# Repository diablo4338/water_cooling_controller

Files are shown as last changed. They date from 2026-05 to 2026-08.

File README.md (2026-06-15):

# PC Water Cooling Controller

An end-to-end fan controller solution built around a custom PCB and an `ESP32-C3` controller. The repository covers the full product scope: device firmware, a desktop application for Windows and Linux, PCB manufacturing files, and the bill of materials.

The controller is designed for:
- up to 4 fans;
- up to 4 `10k` thermistors.

The desktop application works over BLE and supports pairing mode, controller connection, telemetry monitoring, and cooling parameter updates. The hardware lives in `hardware/`, and the release pipeline builds a unified set of artifacts through [`.github/workflows/release.yml`](.github/workflows/release.yml).

## Repository structure
- [`firmware/`](firmware/README.md) - `ESP-IDF` firmware for `ESP32-C3`.
- [`pcwcc/`](pcwcc/README.md) - desktop GUI for Windows and Linux.
- [`hardware/`](hardware/README.md) - KiCad project, BOM, and production exports for the PCB.
- [`tests/raspberry/`](tests/raspberry/README.md) - Raspberry Pi helper for hardware integration tests.
- [`docker/`](docker/README.md) - local Docker environment for release-build verification.
- [`docs/`](docs/) - additional notes on architecture, CLI, release flow, and hardware.

## Release artifacts
The `scripts/make_release.sh` script and the `Release` workflow produce:
- firmware for `ESP32-C3`;
- a Linux `AppImage` for the desktop client;
- a production archive with `Gerber` and `drill` files for PCB manufacturing;
- checksums;
- the BOM is stored separately in [`hardware/production/bom/main.csv`](hardware/production/bom/main.csv).

Build details and structure notes are kept in the `README` files of the corresponding directories.

## License

This project is licensed for non-commercial use only.

Commercial use is not permitted without prior written permission from the author.

See [LICENSE](LICENSE) for details.

## Safety disclaimer

This is an experimental DIY hardware/software project. Use it at your own risk.
Incorrect wiring, firmware, configuration, or installation may cause hardware
damage, overheating, fire, or injury.

See [DISCLAIMER.md](DISCLAIMER.md).

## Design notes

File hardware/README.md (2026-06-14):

# Hardware

Hardware assets for the controller: the KiCad board project, PCB production files, and the bill of materials.

## Structure
- `kicad/` - KiCad project sources:
  - `main.kicad_pro` - project file;
  - `main.kicad_sch` - top-level schematic;
  - `main.kicad_pcb` - PCB;
  - additional schematic sheets: `ads`, `esp`, `fan_power`, `fans`, `ina`, `power`.
- `production/gerbers/` - `Gerber` files for board fabrication.
- `production/drill/` - drill files.
- `production/bom/main.csv` - BOM.
- `production/schematic-pdf/main.pdf` - schematic PDF export.

## Production artifacts
[`../scripts/build_hardware.sh`](../scripts/build_hardware.sh) builds the following archive in `dist/`:

```text
pc-water-cooling-controller-<version>-hardware-gerbers-drill.zip
```

It contains:
- all files from `production/gerbers/`;
- all files from `production/drill/`.

The BOM is kept in the repository separately and is not packed by this script, so it should be treated as an independent manufacturing artifact.

## Practical use
If the task is related to board manufacturing or revision work, this directory contains the working inputs:
- source files for schematic and PCB changes;
- ready-to-send fabrication exports;
- the current component list.

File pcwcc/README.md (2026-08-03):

# PCWCC

A desktop application for controlling the device over BLE. The GUI is built with `PySide6`, and the BLE layer uses `bleak`. The application runs on Linux and Windows; Linux releases are packaged as `AppImage`.

## Features
- scanning for the controller in pairing mode;
- pairing and subsequent application-level authorization;
- connecting to the device and reading temperatures in real time;
- reading and applying cooling parameters;
- BLE session diagnostics through debug mode.

Application-local data:
- `paired_devices.json` - trusted device database;
- `host_key.pem` - host private key used for pairing.

## Structure
- `src/pcwcc/core_logic/` - BLE protocol, codecs, pairing, control, and storage.
- `src/pcwcc/gui_logic/` - UI logic.
- `src/pcwcc/main.py` - entry point.
- `tests/` - unit and integration tests for the client.
- `packaging/` - desktop packaging assets.
- `pcwcc.spec` - `PyInstaller` configuration.

## Run

The application requires Python 3.11, 3.12, or 3.13. Python 3.14 is not
currently supported. Runtime and development dependencies are declared in
[`pyproject.toml`](pyproject.toml); the project does not use a separate
`requirements.txt`.

### Windows (PowerShell)

From the repository root, create a virtual environment using Python 3.13:

```powershell
py -3.13 -m venv .venv
```

Install the application and its development dependencies:

```powershell
.\.venv\Scripts\python.exe -m pip install --upgrade pip
.\.venv\Scripts\python.exe -m pip install -e ".\pcwcc[dev]"
```

Run the application:

```powershell
.\.venv\Scripts\python.exe -m pcwcc.main
```

Run it with extended BLE diagnostics:

```powershell
.\.venv\Scripts\python.exe -m pcwcc.main --debug
```

The editable installation (`-e`) means source code changes are picked up when
the application is restarted; reinstalling the package after each change is
not required.

If `py -3.13` reports that no suitable Python installation was found, install
64-bit Python 3.13 first, then repeat the commands above.

### Linux

From the `pcwcc/` directory, after installing the project dependencies:

```bash
python3 -m venv .venv
.venv/bin/python -m pip install -e ".[dev]"
PYTHONPATH=src python -m pcwcc.main
```

Alternatively, from the repository root:

```bash
make run-app
```

`make run-app` installs the application and its development dependencies from
`pcwcc/pyproject.toml` before starting it. To install without starting the GUI,
use:

```bash
make install-app
```

For extended BLE diagnostics:

```bash
make run-app APP_ARGS=--debug
```

## Tests
Unit tests:

```bash
PYTHONPATH=src python -m pytest -c pytest.ini -q -m "not integration"
```

Integration tests from the repository root:

```bash
PYTHONPATH=pcwcc/src python -m pytest -c pcwcc/pytest.ini -q -m integration
```

## Environment variables
Application:
- `BLE_SCAN_TIMEOUT_S`
- `BLE_RESOLVE_TIMEOUT_S`
- `BLE_CONNECT_TIMEOUT_S`
- `BLE_PAIR_TIMEOUT_S`
- `BLE_AUTH_TIMEOUT_S`
- `BLE_METRICS_TIMEOUT_S`
- `BLE_METRICS_RETRIES`
- `BLE_METRICS_RECONNECT_DELAY_S`
- `BLE_RESOLVE_BEFORE_CONNECT`
- `BLE_USE_SERVICE_FILTER`
- `BLE_WINRT_USE_CACHED_SERVICES`
- `BLE_WINRT_ADDRESS_TYPE`
- `GUI_ACTION_DEFAULT_TIMEOUT_S`
- `GUI_ACTION_SCAN_TIMEOUT_S`
- `GUI_ACTION_PAIR_TIMEOUT_S`
- `GUI_ACTION_CONNECT_TIMEOUT_S`
- `GUI_ACTION_DISCONNECT_TIMEOUT_S`

Integration tests:
- `BLE_ADDRESS`
- `BLE_ADAPTER`
- `SCAN_TIMEOUT_S`
- `CONNECT_TIMEOUT_S`
- `PRESS_BASE_URL`
- `PRESS_TIMEOUT_S`
- `PRESS_RETRIES`
- `PRESS_NO_RESPONSE`

## Packaging
The Linux `AppImage` is built by [`../scripts/build_appimage.sh`](../scripts/build_appimage.sh). Details are in [`packaging/appimage/README.md`](packaging/appimage/README.md).

### Windows executable

From the repository root, after installing the development dependencies, build
the Windows application with PyInstaller:

```powershell
.\.venv\Scripts\python.exe -m PyInstaller `
  --name PCWCC `
  --windowed `
  --onedir `
  --paths ".\pcwcc\src" `
  ".\pcwcc\src\pcwcc\main.py"
```

The executable is written to `dist\PCWCC\PCWCC.exe`. Windows builds disable
filtered and cached WinRT GATT service discovery by default to avoid
`ERROR_BAD_COMMAND (0x80070016)` with the controller. The behaviour can still
be overridden with `BLE_USE_SERVICE_FILTER` and
`BLE_WINRT_USE_CACHED_SERVICES`.

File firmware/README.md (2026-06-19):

# Firmware

`ESP-IDF` firmware for the `ESP32-C3` controller. It implements the BLE protocol, pairing and authorization, temperature acquisition from 4 channels, and control for 4 fans.

## Structure
- `src/ble_protocol/` - BLE services, GATT, pairing, control, and application logic.
- `src/metrics/` - temperature metric acquisition.
- `src/i2c_bus/` - shared I2C bus support.
- `tests/` - firmware tests enabled with `PAIR_RUN_TESTS=1`.
- `include/` - shared top-level headers if they need to be moved out of component-local structure.
- `sdkconfig`, `sdkconfig.defaults` - build configuration.

## Build and flash
From the repository root:

```bash
make fw
```

Manual `ESP-IDF` invocation:

```bash
. ~/esp/esp-idf/export.sh
idf.py -C firmware fullclean build flash
```

Test firmware:

```bash
make fw-test
```

This build enables `PAIR_RUN_TESTS=1`.

## Release output
[`scripts/build_firmware.sh`](../scripts/build_firmware.sh) builds and places the following into `dist/`:
- the main `.bin`;
- `.elf`;
- `.map`, if generated;
- `bootloader.bin`;
- `partition-table.bin`;
- a flashing note file.
- a `.zip` archive containing the full firmware artifact set.

## Related docs
- [`../docs/firmware.md`](../docs/firmware.md) - short firmware summary.
- [`../docs/architecture.md`](../docs/architecture.md) - architecture notes and protocol details.

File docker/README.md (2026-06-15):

# Docker release build config

Docker configuration for release builds used by the GitHub Actions [`Release`](../.github/workflows/release.yml) workflow. It defines the container environment for firmware and desktop packaging, including `Ubuntu 20.04`, `Python 3.12`, `OpenSSL 3`, `ESP-IDF`, AppImage tooling, and release artifact generation.

This is not the product runtime environment and not the main development flow. Its purpose is to provide the CI build environment and let the same release pipeline be reproduced locally when needed.

## Build the local image
From the `docker/` directory:

```bash
sudo docker build --no-cache \
  -t pcwcc-ubuntu20-build:local \
  -f Dockerfile.ubuntu20 .
```

After that, the expected flow is to run the release scripts from `scripts/` inside the container instead of assembling artifacts manually.

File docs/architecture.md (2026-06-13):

# Architecture

The project is a PC water cooling controller. The system consists of a GUI app (BLE client), device firmware, and a small HTTP service used by integration tests.

Key artifacts:
- `paired_devices.json` - trusted devices database on the host.
- `host_key.pem` - persistent host private key (P-256) used for pairing.

## App (pcwcc)
- `pcwcc/src/pcwcc/config.py` - loads configuration from env, shared timeouts/retries for BLE and GUI.
- `pcwcc/src/pcwcc/core.py` - public BLE API and protocol (pair/auth/metrics/config/operations). Used by GUI and tests.
- `pcwcc/src/pcwcc/presentation.py` - pure UI state logic (Actions, AppState, derive_ui).
- `pcwcc/src/pcwcc/gui.py` - PySide6 GUI and `BleWorker` that calls `BleAppCore`.
- `pcwcc/src/pcwcc/main.py` - minimal GUI entrypoint.
- `pcwcc/tests/` - unit and integration tests, run through `pcwcc/src/pcwcc/core.py`.

## Firmware (firmware/)
- `firmware/src/ble_protocol/app/main.c` - `app_main`, NVS, NimBLE, timers, metrics init.
- `firmware/src/ble_protocol/ble/gap.c` - advertising, connect/disconnect, PAIR/MAIN mode selection.
- `firmware/src/ble_protocol/ble/gatt.c` - GATT database (PAIR/MAIN/METRICS), read/write callbacks.
- `firmware/src/ble_protocol/ble/uuid.c` - UUID strings, firmware source of truth.
- `firmware/src/ble_protocol/pairing/state.c` - main access state machine (trusted/unauth/authed) and session handles.
- `firmware/src/ble_protocol/pairing/pair_state.c` - pairing flow steps.
- `firmware/src/ble_protocol/pairing/pair_mode.c` - separate 60-second pairing window and per-session ECDH material.
- `firmware/src/ble_protocol/pairing/conn_guard.c` - connection handle constraints.
- `firmware/src/ble_protocol/pairing/crypto.c`, `ecdh.c`, `host_verify.c` - cryptography and host identity checks.
- `firmware/src/ble_protocol/pairing/storage.c` - ring-buffer storage for up to 5 trusted host/key entries in NVS.
- `firmware/src/ble_protocol/ble/metrics_ble.c` - notify/handle metrics over BLE.
- `firmware/src/metrics/` - metrics source (ADS1115 and aggregation).
- `firmware/tests/` - firmware test sources compiled when `PAIR_RUN_TESTS=1`.
- `firmware/build/` - ESP-IDF build artifacts.

## Support service (tests/raspberry/)
- `tests/raspberry/app.py` - HTTP endpoint for the Raspberry Pi GPIO button, used by integration tests.

## BLE protocol surface
GATT services are split by responsibility:
- `PAIR_SVC` - pairing and initial key exchange.
- `MAIN_SVC` - authorization before data access.
- `METRICS_SVC` - temperature metrics (notify).
- `CONFIG_SVC` - cooling system parameters and status.
- `OPERATIONS_SVC` - maintenance operations (for example, fan calibration).

UUID constants must be synchronized between firmware (`firmware/src/ble_protocol/ble/uuid.c`) and the app (`pcwcc/src/pcwcc/core.py`).

## Public API Contract
Any changes in `pcwcc/src/pcwcc/core.py` must be reflected in tests and the GUI. This file is the source of truth for BLE behavior.
UUID constants in `pcwcc/src/pcwcc/core.py` must match `firmware/src/ble_protocol/ble/uuid.c`.
Actions from `pcwcc/src/pcwcc/presentation.py` are the public contract between the GUI and UI logic. Renaming Actions requires updating UI bindings and tests.
All interactive GUI elements are tagged with `actionId = Action.name` and used for smoke checks.

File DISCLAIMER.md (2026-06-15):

# Disclaimer

This project is an experimental DIY hardware and software project.

It is provided without any warranty. Use it at your own risk.

Incorrect wiring, firmware bugs, incorrect configuration, component failure, or
improper installation may cause overheating, hardware damage, fire, electric
shock, data loss, injury, or other damage.

The author is not responsible for any damage, loss, injury, fire, electrical
failure, or other consequences caused by building, modifying, installing, or
using this project.

You are responsible for checking the design, selecting appropriate components,
adding fuses and protections, testing the device, and ensuring that it is safe
for your use case.

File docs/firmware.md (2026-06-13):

# Firmware

The ESP-IDF project lives under `firmware/`.

- Components: `firmware/src/ble_protocol`, `firmware/src/metrics`, `firmware/src/i2c_bus`
- Firmware tests: `firmware/tests/`
- Build entry: `firmware/CMakeLists.txt`
- Active config: `firmware/sdkconfig`

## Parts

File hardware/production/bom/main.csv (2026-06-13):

Reference | Qty | Value | DNP | Exclude from BOM | Exclude from Board | Footprint | Datasheet
BZ1 | 1 | Buzzer |  |  |  | Connector_PinHeader_2.54mm:PinHeader_1x02_P2.54mm_Vertical
C1,C2,C3,C4,C8,C9,C20 | 7 | 0.1 |  |  |  | Capacitor_SMD:C_0805_2012Metric_Pad1.18x1.45mm_HandSolder
C5 | 1 | 4.7 |  |  |  | Capacitor_SMD:C_0805_2012Metric_Pad1.18x1.45mm_HandSolder
C6,C7,C25 | 3 | 1 |  |  |  | Capacitor_SMD:C_0805_2012Metric_Pad1.18x1.45mm_HandSolder
C10 | 1 | 280 |  |  |  | Capacitor_THT:CP_Radial_D8.0mm_P3.50mm
C17,C18,C19,C22,C23,C24 | 6 | 10 |  |  |  | Capacitor_SMD:C_0805_2012Metric_Pad1.18x1.45mm_HandSolder
C21 | 1 | 10p |  |  |  | Capacitor_SMD:C_0805_2012Metric_Pad1.18x1.45mm_HandSolder
D1 | 1 | D_Small |  |  |  | Diode_SMD:D_0805_2012Metric_Pad1.15x1.40mm_HandSolder
D2 | 1 | PD3S120LQ |  |  |  | Custom:323_2
D3 | 1 | 1N4148WS-HG3_A-08 |  |  |  | Diode_SMD:D_SOD-323_HandSoldering | https://www.diodes.com/assets/Datasheets/ds30396.pdf
J1,J2,J3,J4 | 4 | Conn_01x02_Pin |  |  |  | Connector_PinHeader_2.54mm:PinHeader_1x02_P2.54mm_Horizontal
J5,J6,J7,J8 | 4 | Conn_01x04_Pin |  |  |  | Connector:FanPinHeader_1x04_P2.54mm_Vertical
J9,J10 | 2 | Conn_01x03_Socket |  |  |  | Connector_PinHeader_2.54mm:PinHeader_1x02_P2.54mm_Vertical
J11 | 1 | Conn_01x03_Socket |  |  |  | Custom:sata
L1 | 1 | DE1207-56(DR125-560-R EATON ELECTRONICS) |  |  |  | Custom:SRN4018
Q1 | 1 | MMFTP3334K |  |  |  | Package_TO_SOT_SMD:SOT-23-3 | https://ngspice.sourceforge.io/docs/ngspice-html-manual/manual.xhtml#cha_MOSFETs
Q2,Q3 | 2 | NXV40UNR |  |  |  | Package_TO_SOT_SMD:SOT-23-3 | https://ngspice.sourceforge.io/docs/ngspice-html-manual/manual.xhtml#cha_MOSFETs
Q4 | 1 | BCV71 |  |  |  | Package_TO_SOT_SMD:SOT-23-3 | https://ngspice.sourceforge.io/docs/ngspice-html-manual/manual.xhtml#cha_BJTs
R1,R2,R3,R4 | 4 | 330 |  |  |  | Resistor_SMD:R_0805_2012Metric_Pad1.20x1.40mm_HandSolder
R5,R6,R7,R8,R9,R14,R20,R24,R25,R30 | 10 | 4k7 |  |  |  | Resistor_SMD:R_0805_2012Metric_Pad1.20x1.40mm_HandSolder
R10,R12,R18,R19,R23,R27,R34,R36 | 8 | 100k |  |  |  | Resistor_SMD:R_0805_2012Metric_Pad1.20x1.40mm_HandSolder
R11,R13 | 2 | 2k2 |  |  |  | Resistor_SMD:R_0805_2012Metric_Pad1.20x1.40mm_HandSolder
R15,R16,R33 | 3 | 1k |  |  |  | Resistor_SMD:R_0805_2012Metric_Pad1.20x1.40mm_HandSolder
R17 | 1 | WSL2512R0470FEA |  |  |  | Resistor_SMD:R_2512_6332Metric_Pad1.40x3.35mm_HandSolder
R21 | 1 | 124k |  |  |  | Resistor_SMD:R_0805_2012Metric_Pad1.20x1.40mm_HandSolder
R22 | 1 | 10k |  |  |  | Resistor_SMD:R_0805_2012Metric_Pad1.20x1.40mm_HandSolder
R26,R35 | 2 | 100 |  |  |  | Resistor_SMD:R_0805_2012Metric_Pad1.20x1.40mm_HandSolder
R28 | 1 | 4k02 |  |  |  | Resistor_SMD:R_0805_2012Metric_Pad1.20x1.40mm_HandSolder
R29 | 1 | 61k9 |  |  |  | Resistor_SMD:R_0805_2012Metric_Pad1.20x1.40mm_HandSolder
R31,R32 | 2 | 10 |  |  |  | Resistor_SMD:R_0805_2012Metric_Pad1.20x1.40mm_HandSolder
SW1 | 1 | PAIR |  |  |  | Custom:smd button
SW2 | 1 | RESET |  |  |  | Custom:smd button
SW3 | 1 | BOOT |  |  |  | Custom:smd button
U1 | 1 | ESP32-C3-WROOM-02 |  |  |  | RF_Module:ESP32-C3-WROOM-02 | https://www.espressif.com/sites/default/files/documentation/esp32-c3-wroom-02_datasheet_en.pdf
U2 | 1 | TPS7A02-3.3 |  |  |  | Package_TO_SOT_SMD:SOT-23-5 | https://www.ti.com/lit/ds/symlink/tps7a05.pdf
U3 | 1 | TMUX1104DGSR |  |  |  | Ti:DGS0010A-IPC_C | https://www.ti.com/lit/gpn/tmux1104
U4 | 1 | ADS1115IDGS |  |  |  | Ti:DGS0010A_N | http://www.ti.com/lit/ds/symlink/ads1113.pdf
U5 | 1 | MCP16331T-E/CH |  |  |  | Package_TO_SOT_SMD:SOT-23-6 | http://ww1.microchip.com/downloads/en/DeviceDoc/20005308C.pdf
U6 | 1 | INA226 |  |  |  | Package_SO:VSSOP-10_3x3mm_P0.5mm | http://www.ti.com/lit/ds/symlink/ina226.pdf

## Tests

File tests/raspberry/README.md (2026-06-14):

# Raspberry button test helper

A small `FastAPI` service for Raspberry Pi that simulates a long hardware-button press over GPIO. It is used by integration tests when the controller must be switched into pairing mode without manual intervention.

## Contents
- `app.py` - HTTP endpoint `GET /press/reset-long` that drives the GPIO pin.
- `requirements.txt` - Raspberry Pi dependencies: `fastapi`, `uvicorn`, `RPi.GPIO`.

## Wiring
- GPIO mode: `BCM`;
- output pin in code: `GPIO_PIN = 17`;
- Raspberry Pi physical header pin for `BCM 17`: `11`;
- signal level: `3.3V`;
- common `GND` between the Raspberry Pi and the target board is required.

The service holds `BCM 17` at `HIGH` for `5.0` seconds and then returns the line to `LOW`.

## Run
From the repository root:

```bash
uvicorn tests.raspberry.app:app --host 0.0.0.0 --port 8001
```

or:

```bash
make run-buttons
```

## Constraints
- `RPi.GPIO` only works on Raspberry Pi with GPIO access;
- if the target board input is not `3.3V` tolerant, use proper level shifting or interface circuitry.

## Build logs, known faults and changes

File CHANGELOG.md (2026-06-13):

# Changelog

## Unreleased
- Restructured repository layout into `docs/`, `pcwcc/src/`, and `firmware/src/`.

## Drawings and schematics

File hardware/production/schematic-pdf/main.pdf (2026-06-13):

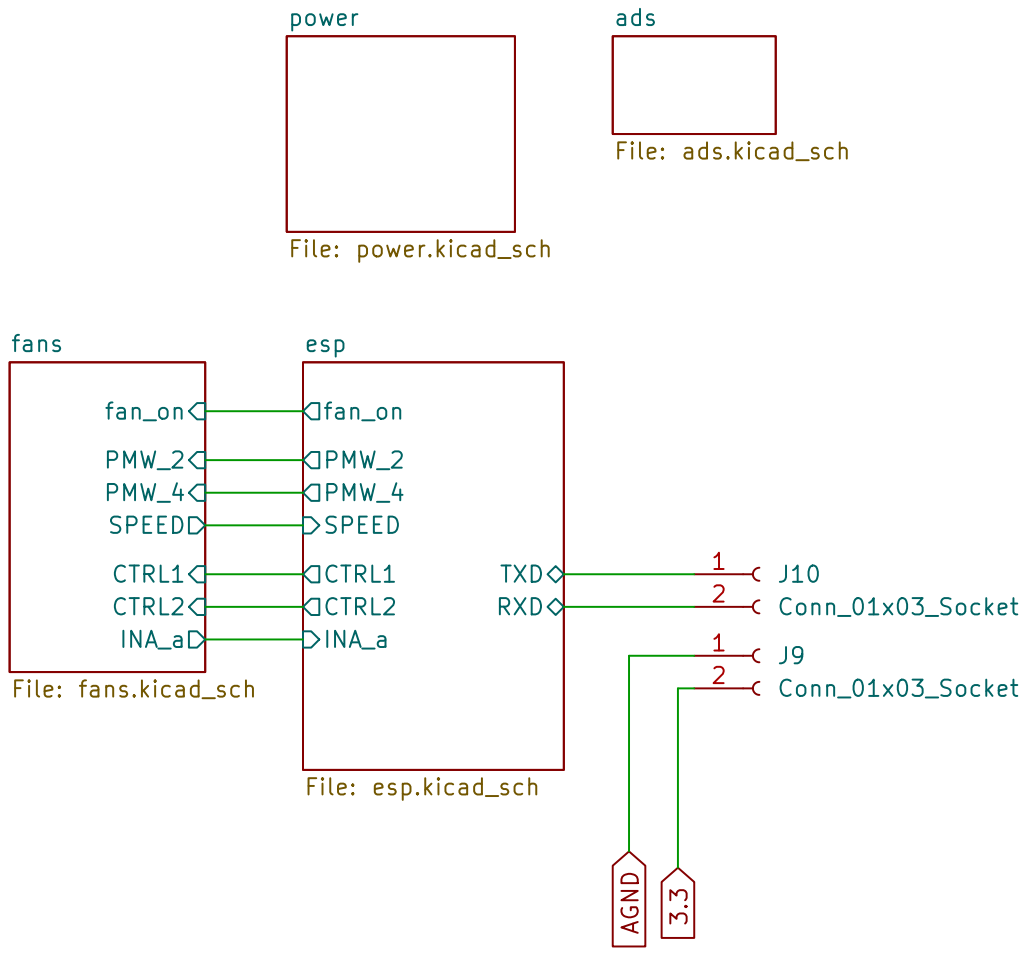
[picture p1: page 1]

Size: A4 | Rev:
KiCad E.D.A. 10.0.3 | Id: 1/7

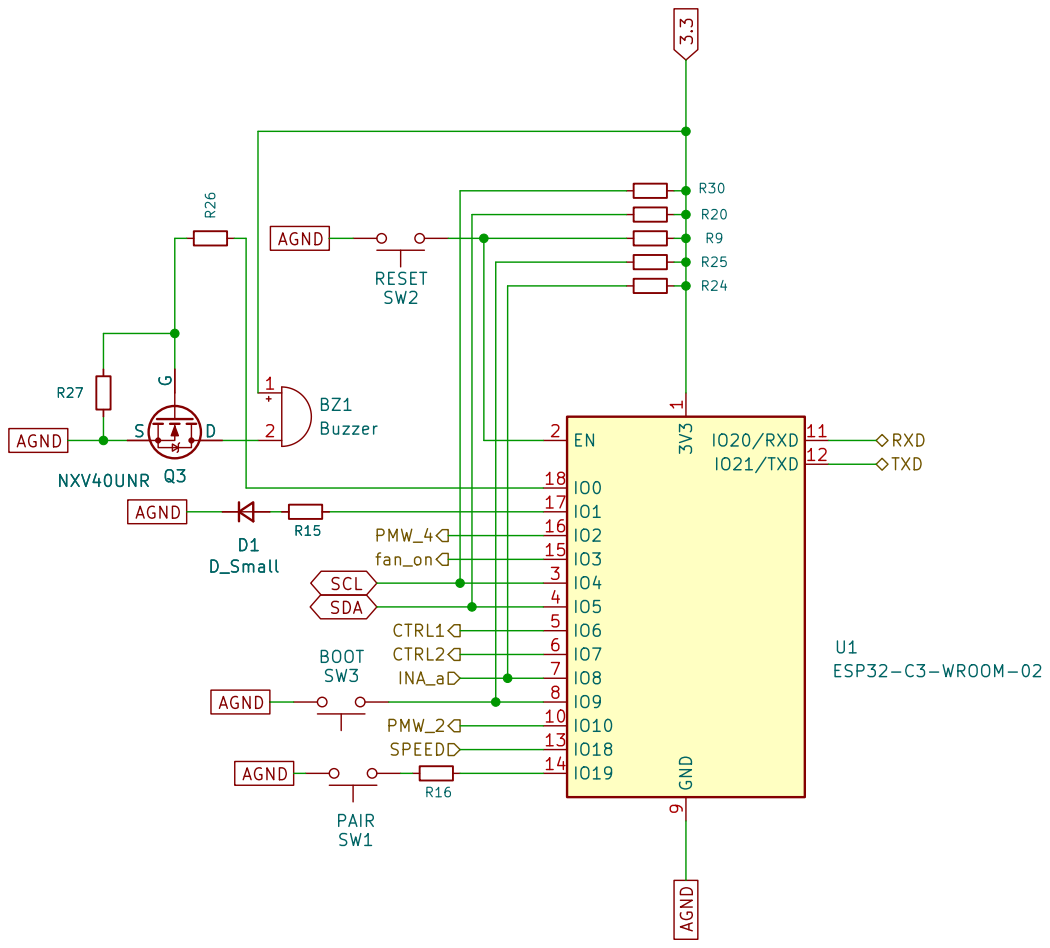
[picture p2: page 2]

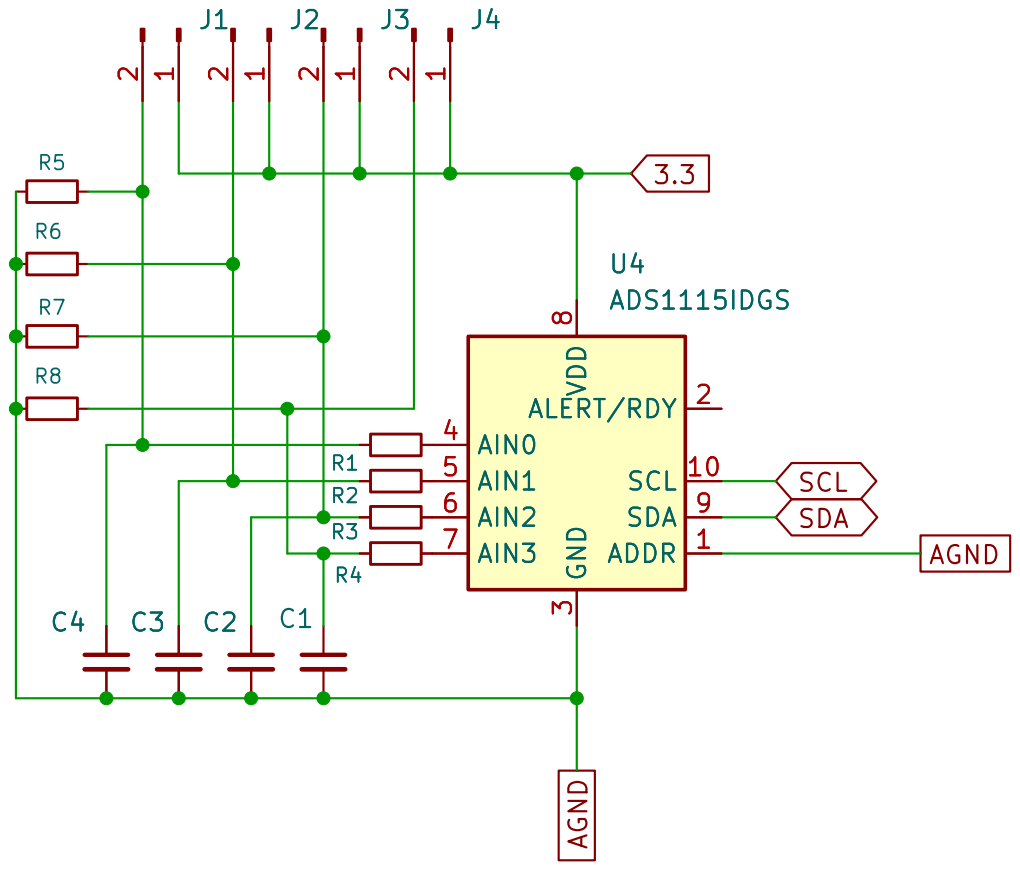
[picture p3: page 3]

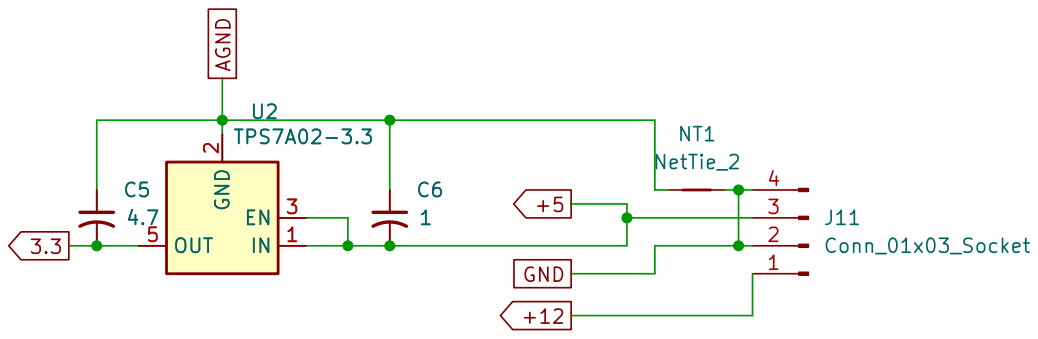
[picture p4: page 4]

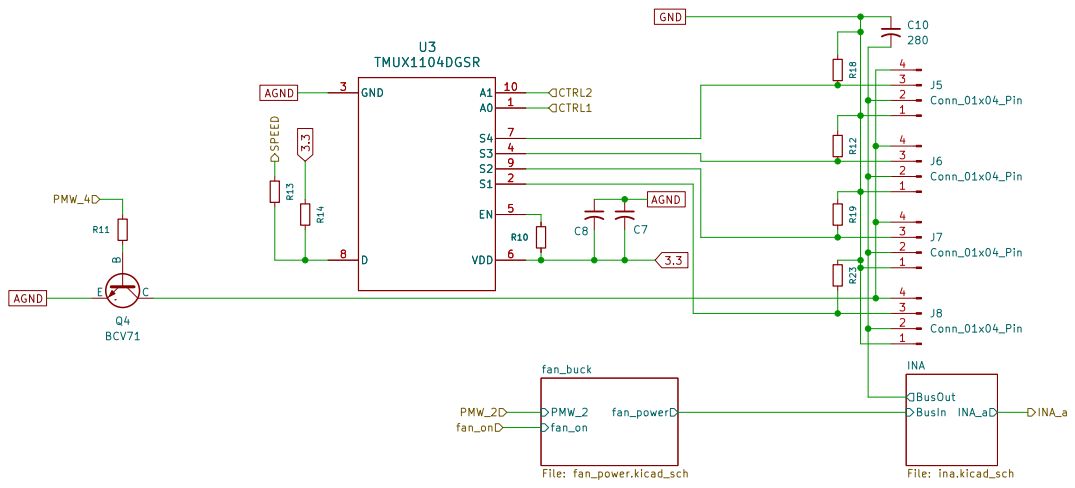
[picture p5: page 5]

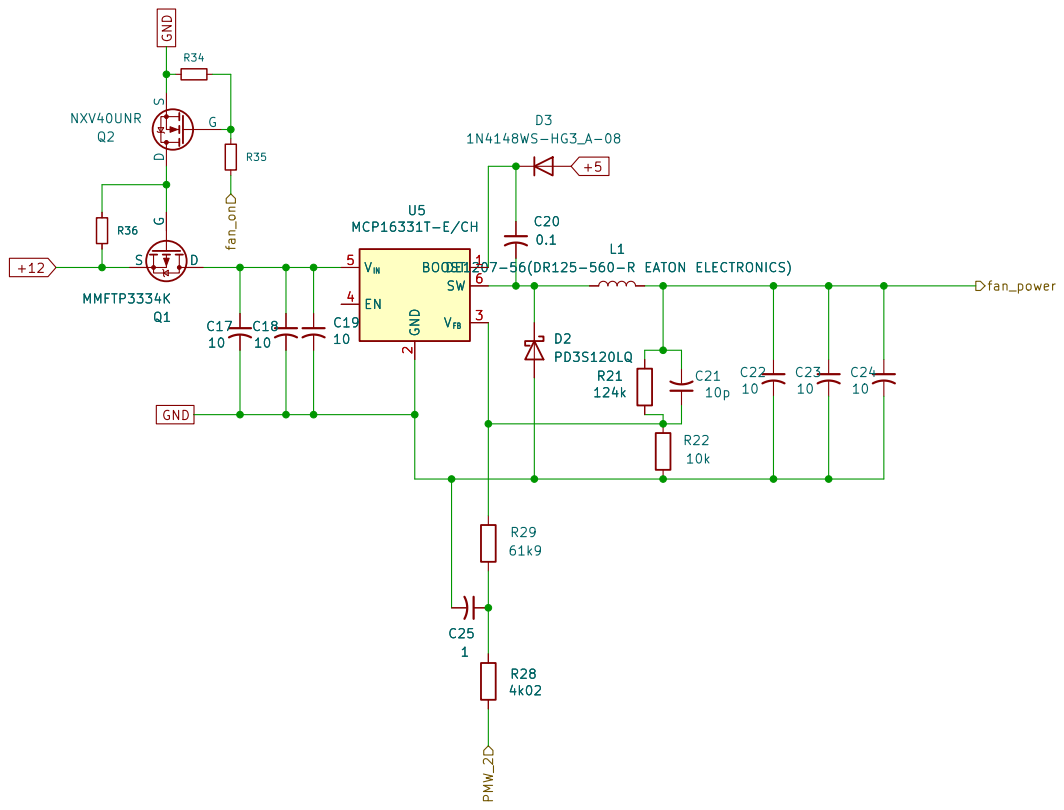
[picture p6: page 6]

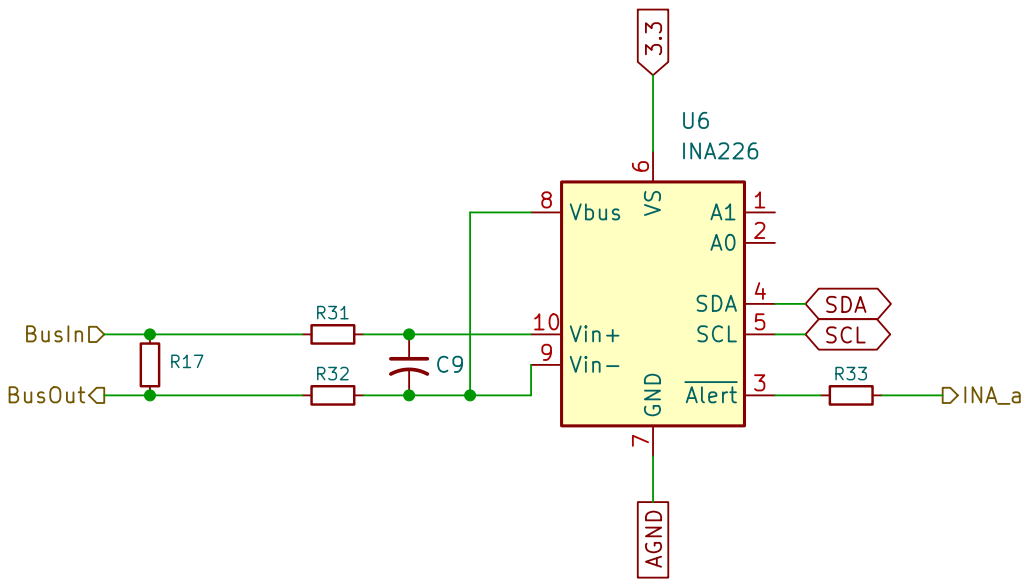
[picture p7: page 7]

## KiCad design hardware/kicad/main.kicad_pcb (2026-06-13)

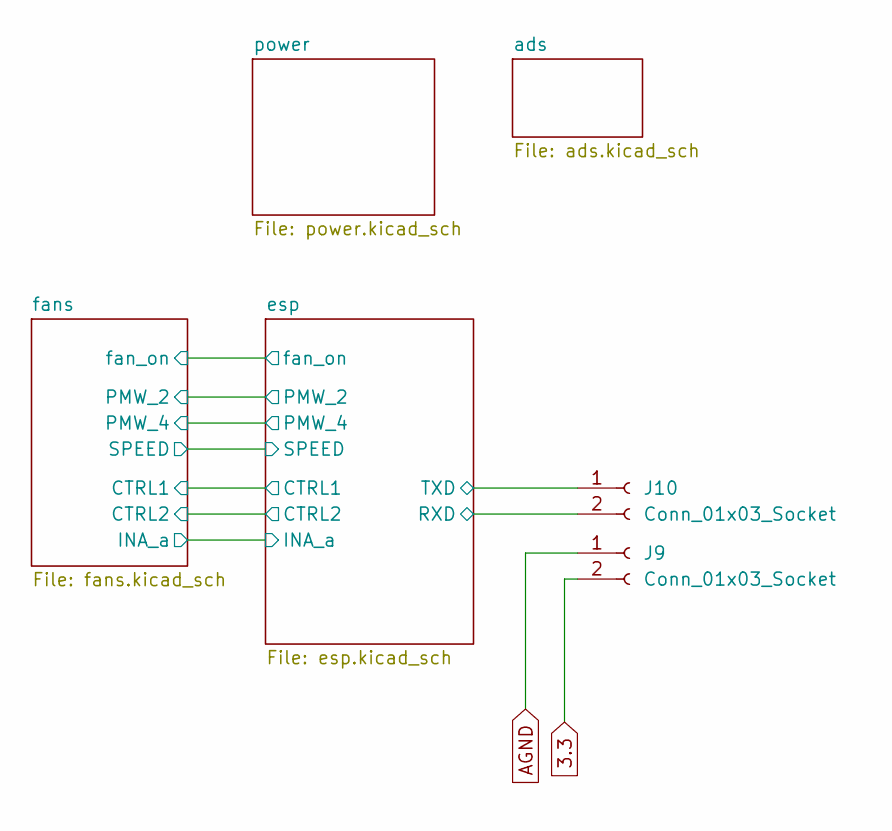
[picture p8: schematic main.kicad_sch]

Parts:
J9, J10: Conn_01x03_Socket; PinHeader_1x02_P2.54mm_Vertical

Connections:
3.3: J9.2; also elsewhere on the board
/esp/RXD: J10.2; also elsewhere on the board
/esp/TXD: J10.1; also elsewhere on the board
AGND: J9.1; also elsewhere on the board

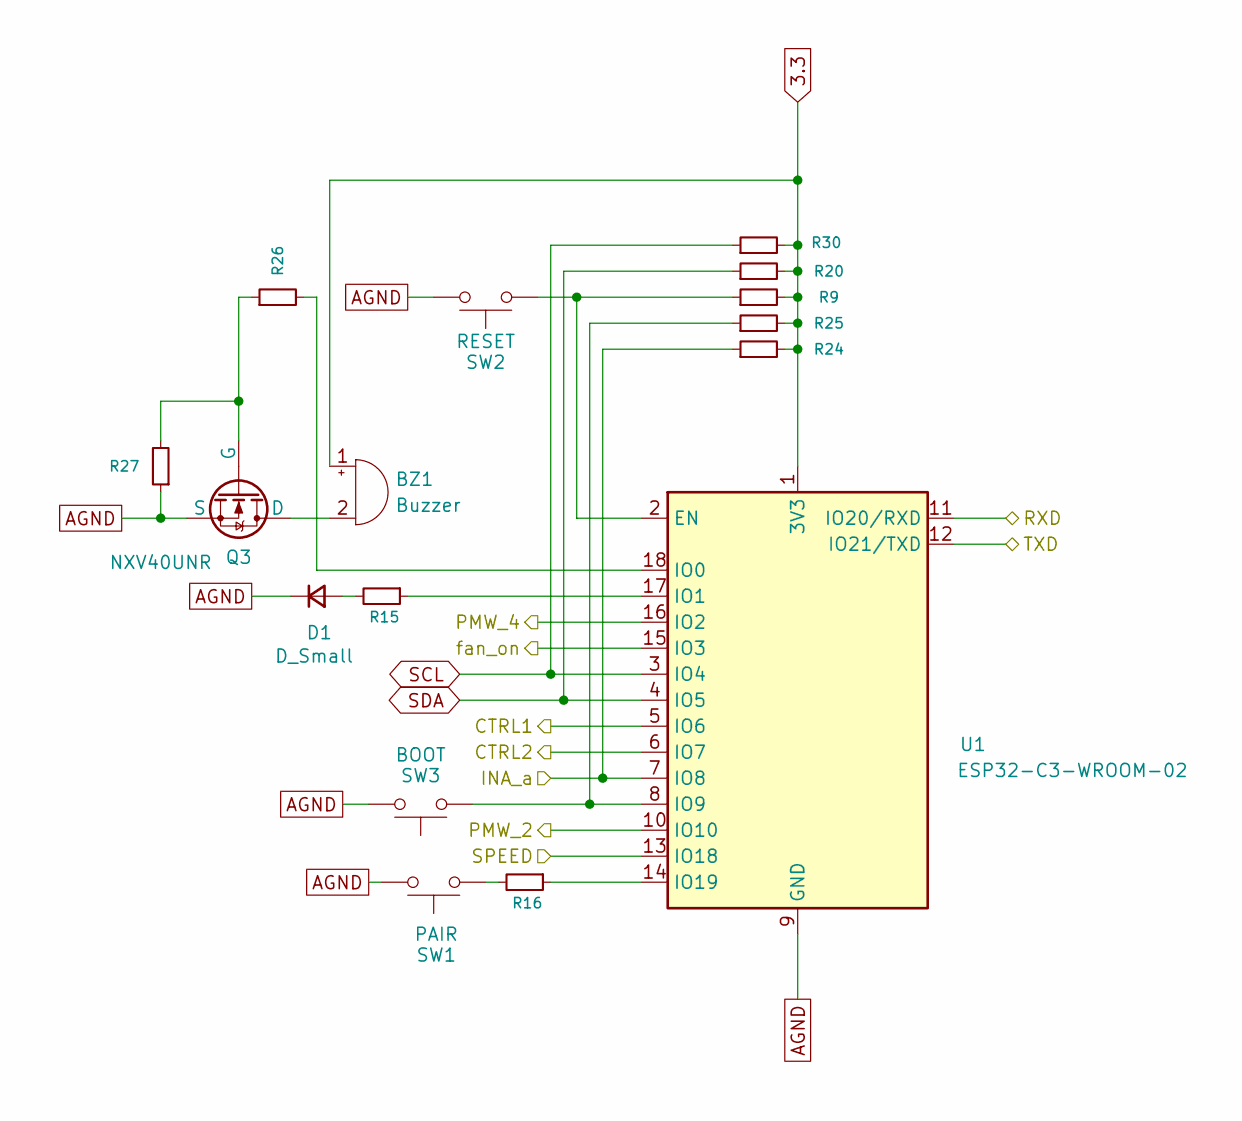
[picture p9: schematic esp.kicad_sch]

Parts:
BZ1: Buzzer; PinHeader_1x02_P2.54mm_Vertical
D1: D_Small; D_0805_2012Metric_Pad1.15x1.40mm_HandSolder
Q3: NXV40UNR; SOT-23-3
R9, R20, R24, R25, R30: 4k7; R_0805_2012Metric_Pad1.20x1.40mm_HandSolder
R15, R16: 1k; R_0805_2012Metric_Pad1.20x1.40mm_HandSolder
R26: 100; R_0805_2012Metric_Pad1.20x1.40mm_HandSolder
R27: 100k; R_0805_2012Metric_Pad1.20x1.40mm_HandSolder
SW1: PAIR; smd button
SW2: RESET; smd button
SW3: BOOT; smd button
U1: ESP32-C3-WROOM-02

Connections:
3.3: BZ1.1 (+), R9.2, R20.2, R24.2, R25.2, R30.2, U1.1 (3V3); also elsewhere on the board
/esp/CTRL1: U1.5 (IO6); also elsewhere on the board
/esp/CTRL2: U1.6 (IO7); also elsewhere on the board
/esp/INA_a: R24.1, U1.7 (IO8); also elsewhere on the board
/esp/PMW_2: U1.10 (IO10); also elsewhere on the board
/esp/PMW_4: U1.16 (IO2); also elsewhere on the board
/esp/RXD: U1.11 (IO20/RXD); also elsewhere on the board
/esp/SPEED: U1.13 (IO18); also elsewhere on the board
/esp/TXD: U1.12 (IO21/TXD); also elsewhere on the board
/esp/fan_on: U1.15 (IO3); also elsewhere on the board
AGND: D1.1 (K), Q3.2 (S), R27.1, SW1.2, SW2.2, SW3.2, U1.9 (GND), U1.19 (GND); also elsewhere on the board
unnamed: BZ1.2 (-), Q3.3 (D)
unnamed: D1.2 (A), R15.2
unnamed: Q3.1 (G), R26.1, R27.2
unnamed: R16.2, SW1.1
unnamed: R9.1, SW2.1, U1.2 (EN)
unnamed: R26.2, U1.18 (IO0)
unnamed: R15.1, U1.17 (IO1)
unnamed: R25.1, SW3.1, U1.8 (IO9)
unnamed: R16.1, U1.14 (IO19)
SCL: R30.1, U1.3 (IO4); also elsewhere on the board
SDA: R20.1, U1.4 (IO5); also elsewhere on the board

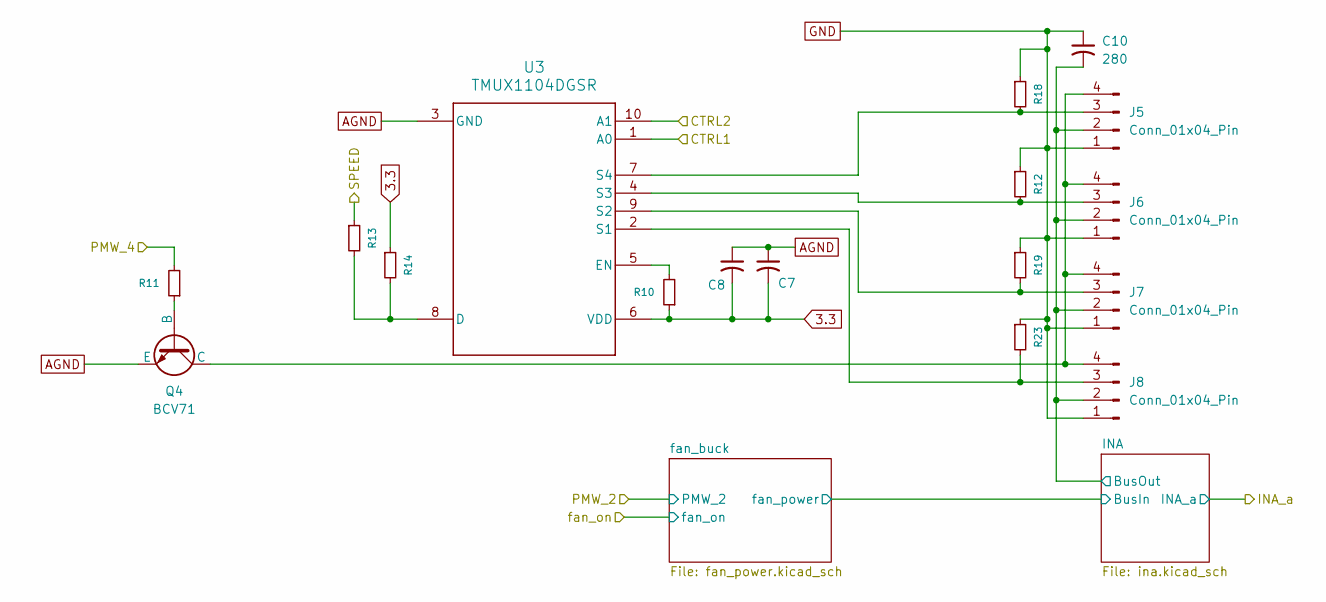
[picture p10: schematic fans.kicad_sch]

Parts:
C7: 1; C_0805_2012Metric_Pad1.18x1.45mm_HandSolder
C8: 0.1; C_0805_2012Metric_Pad1.18x1.45mm_HandSolder
C10: 280; CP_Radial_D8.0mm_P3.50mm
J5, J6, J7, J8: Conn_01x04_Pin; FanPinHeader_1x04_P2.54mm_Vertical
Q4: BCV71; SOT-23-3
R10, R12, R18, R19, R23: 100k; R_0805_2012Metric_Pad1.20x1.40mm_HandSolder
R11, R13: 2k2; R_0805_2012Metric_Pad1.20x1.40mm_HandSolder
R14: 4k7; R_0805_2012Metric_Pad1.20x1.40mm_HandSolder
U3: TMUX1104DGSR; DGS0010A-IPC_C

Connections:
3.3: C7.2, C8.2, R10.1, R14.1, U3.6 (VDD); also elsewhere on the board
/esp/CTRL1: U3.1 (A0); also elsewhere on the board
/esp/CTRL2: U3.10 (A1); also elsewhere on the board
/esp/PMW_4: R11.2; also elsewhere on the board
/esp/SPEED: R13.1; also elsewhere on the board
/fans/INA/BusOut: C10.2, J5.2 (VCC), J6.2 (VCC), J7.2 (VCC), J8.2 (VCC); also elsewhere on the board
AGND: C7.1, C8.1, Q4.2 (E), U3.3 (GND); also elsewhere on the board
GND: C10.1, J5.1 (GND), J6.1 (GND), J7.1 (GND), J8.1 (GND), R12.1, R18.1, R19.1, R23.1; also elsewhere on the board
unnamed: J5.4 (PMW), J6.4 (PMW), J7.4 (PMW), J8.4 (PMW), Q4.3 (C)
unnamed: J5.3 (TAHO), R18.2, U3.7 (S4)
unnamed: J6.3 (TAHO), R12.2, U3.4 (S3)
unnamed: J7.3 (TAHO), R19.2, U3.9 (S2)
unnamed: J8.3 (TAHO), R23.2, U3.2 (S1)
unnamed: Q4.1 (B), R11.1
unnamed: R13.2, R14.2, U3.8 (D)
unnamed: R10.2, U3.5 (EN)

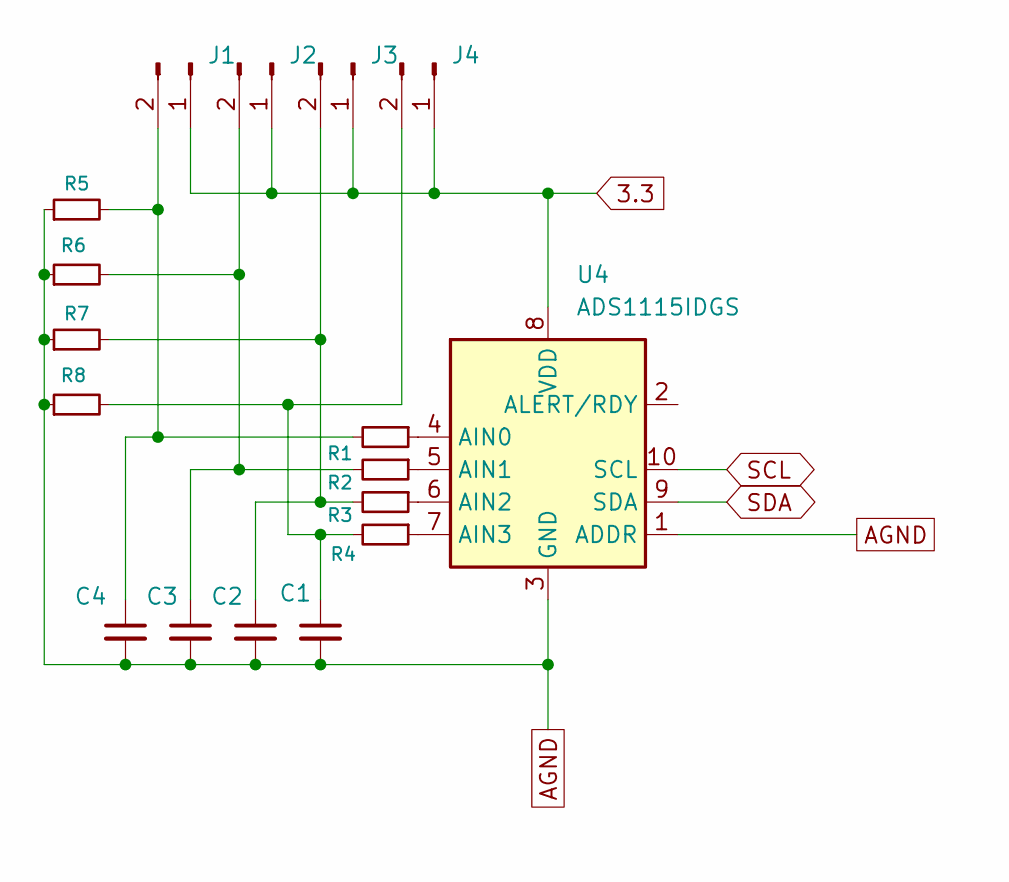
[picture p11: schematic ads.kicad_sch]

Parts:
C1, C2, C3, C4: 0.1; C_0805_2012Metric_Pad1.18x1.45mm_HandSolder
J1, J2, J3, J4: Conn_01x02_Pin; PinHeader_1x02_P2.54mm_Horizontal
R1, R2, R3, R4: 330; R_0805_2012Metric_Pad1.20x1.40mm_HandSolder
R5, R6, R7, R8: 4k7; R_0805_2012Metric_Pad1.20x1.40mm_HandSolder
U4: ADS1115IDGS; DGS0010A_N

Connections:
3.3: J1.1, J2.1, J3.1, J4.1, U4.8 (VDD); also elsewhere on the board
AGND: C1.2, C2.2, C3.2, C4.2, R5.1, R6.1, R7.1, R8.1, U4.1 (ADDR), U4.3 (GND); also elsewhere on the board
unnamed: C4.1, J1.2, R1.2, R5.2
unnamed: C3.1, J2.2, R2.2, R6.2
unnamed: C2.1, J3.2, R3.2, R7.2
unnamed: C1.1, J4.2, R4.2, R8.2
unnamed: R1.1, U4.4 (AIN0)
unnamed: R2.1, U4.5 (AIN1)
unnamed: R3.1, U4.6 (AIN2)
unnamed: R4.1, U4.7 (AIN3)
SCL: U4.10 (SCL); also elsewhere on the board
SDA: U4.9 (SDA); also elsewhere on the board

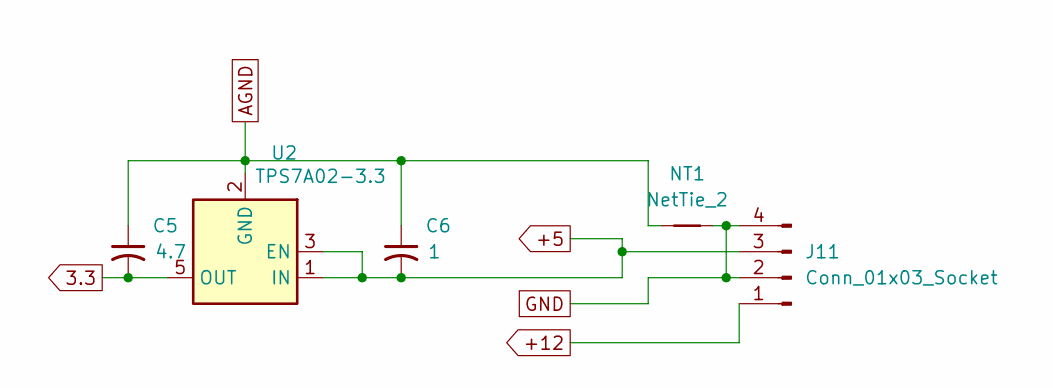
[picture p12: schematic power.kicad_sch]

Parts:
C5: 4.7; C_0805_2012Metric_Pad1.18x1.45mm_HandSolder
C6: 1; C_0805_2012Metric_Pad1.18x1.45mm_HandSolder
J11: Conn_01x03_Socket; sata
NT1: NetTie_2; NetTie-2_SMD_Pad0.5mm
U2: TPS7A02-3.3; SOT-23-5

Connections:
3.3: C5.2, U2.5 (OUT); also elsewhere on the board
+5: C6.2, J11.3 (+5), U2.1 (IN), U2.3 (EN); also elsewhere on the board
+12: J11.1 (+12); also elsewhere on the board
AGND: C5.1, C6.1, NT1.1, U2.2 (GND); also elsewhere on the board
GND: J11.2 (GND), J11.4 (AGND), NT1.2; also elsewhere on the board

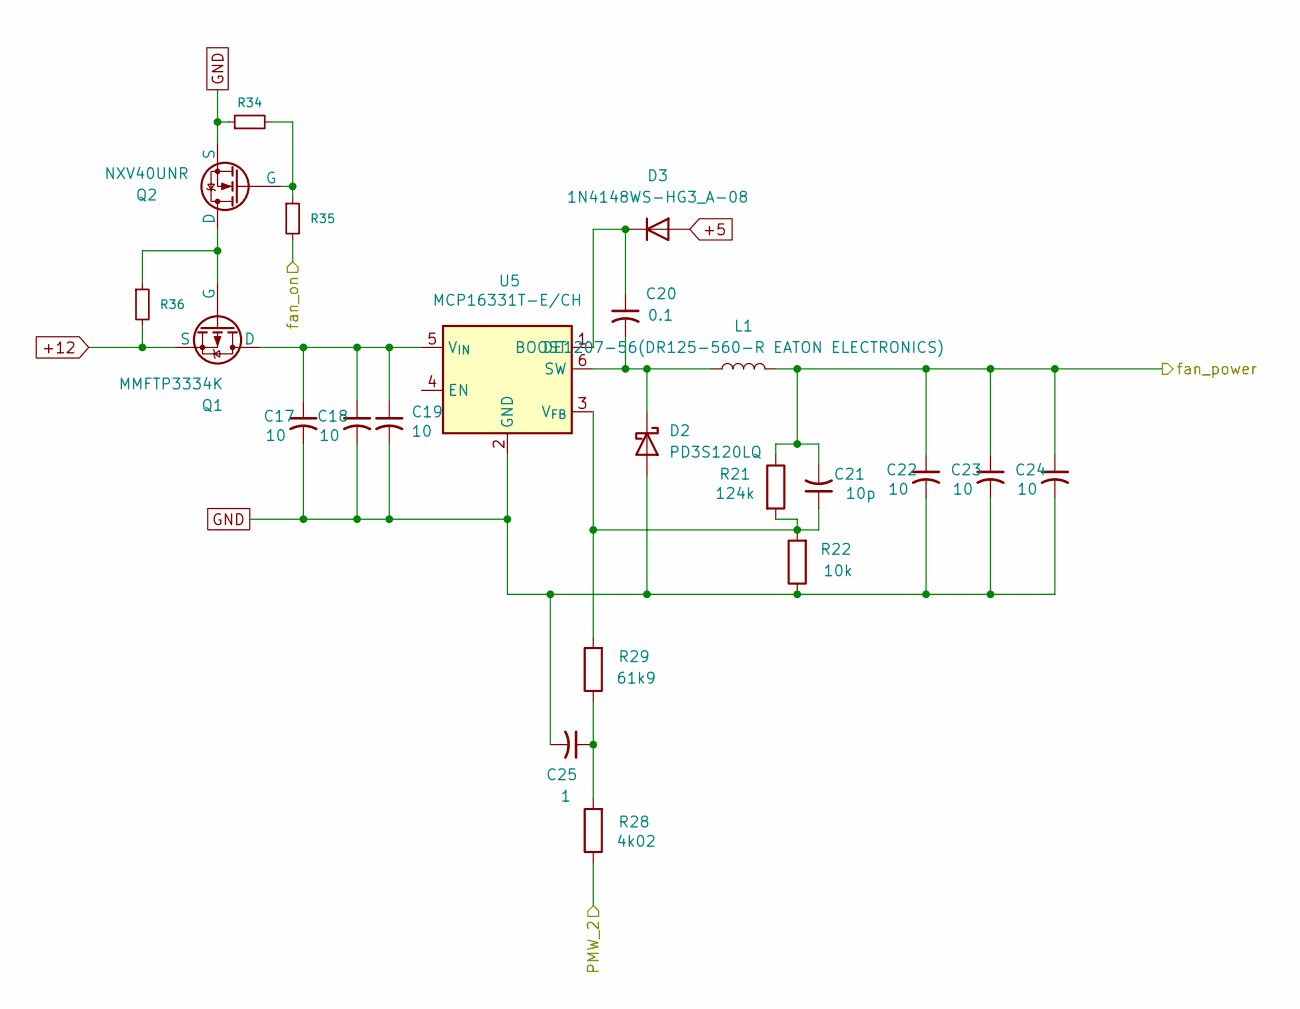
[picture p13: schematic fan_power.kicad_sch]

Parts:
C17, C18, C19, C22, C23, C24: 10; C_0805_2012Metric_Pad1.18x1.45mm_HandSolder
C20: 0.1; C_0805_2012Metric_Pad1.18x1.45mm_HandSolder
C21: 10p; C_0805_2012Metric_Pad1.18x1.45mm_HandSolder
C25: 1; C_0805_2012Metric_Pad1.18x1.45mm_HandSolder
D2: PD3S120LQ; 323_2
D3: 1N4148WS-HG3_A-08; D_SOD-323_HandSoldering
L1: DE1207-56(DR125-560-R EATON ELECTRONICS); SRN4018
Q1: MMFTP3334K; SOT-23-3
Q2: NXV40UNR; SOT-23-3
R21: 124k; R_0805_2012Metric_Pad1.20x1.40mm_HandSolder
R22: 10k; R_0805_2012Metric_Pad1.20x1.40mm_HandSolder
R28: 4k02; R_0805_2012Metric_Pad1.20x1.40mm_HandSolder
R29: 61k9; R_0805_2012Metric_Pad1.20x1.40mm_HandSolder
R34, R36: 100k; R_0805_2012Metric_Pad1.20x1.40mm_HandSolder
R35: 100; R_0805_2012Metric_Pad1.20x1.40mm_HandSolder
U5: MCP16331T-E/CH; SOT-23-6

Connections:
+5: D3.2 (A); also elsewhere on the board
+12: Q1.2 (S), R36.2; also elsewhere on the board
/esp/PMW_2: R28.1; also elsewhere on the board
/esp/fan_on: R35.2; also elsewhere on the board
/fans/INA/BusIn: C21.2, C22.1, C23.1, C24.1, L1.2, R21.1; also elsewhere on the board
GND: C17.2, C18.2, C19.2, C22.2, C23.2, C24.2, C25.2, D2.2 (A), Q2.2 (S), R22.1, R34.1, U5.2 (GND); also elsewhere on the board
unnamed: C25.1, R28.2, R29.1
unnamed: C20.2, D2.1 (K), L1.1, U5.6 (SW)
unnamed: C20.1, D3.1 (K), U5.1 (BOOST)
unnamed: C17.1, C18.1, C19.1, Q1.3 (D), U5.5 (V_{IN})
unnamed: Q1.1 (G), Q2.3 (D), R36.1
unnamed: Q2.1 (G), R34.2, R35.1
unnamed: C21.1, R21.2, R22.2, R29.2, U5.3 (V_{FB})

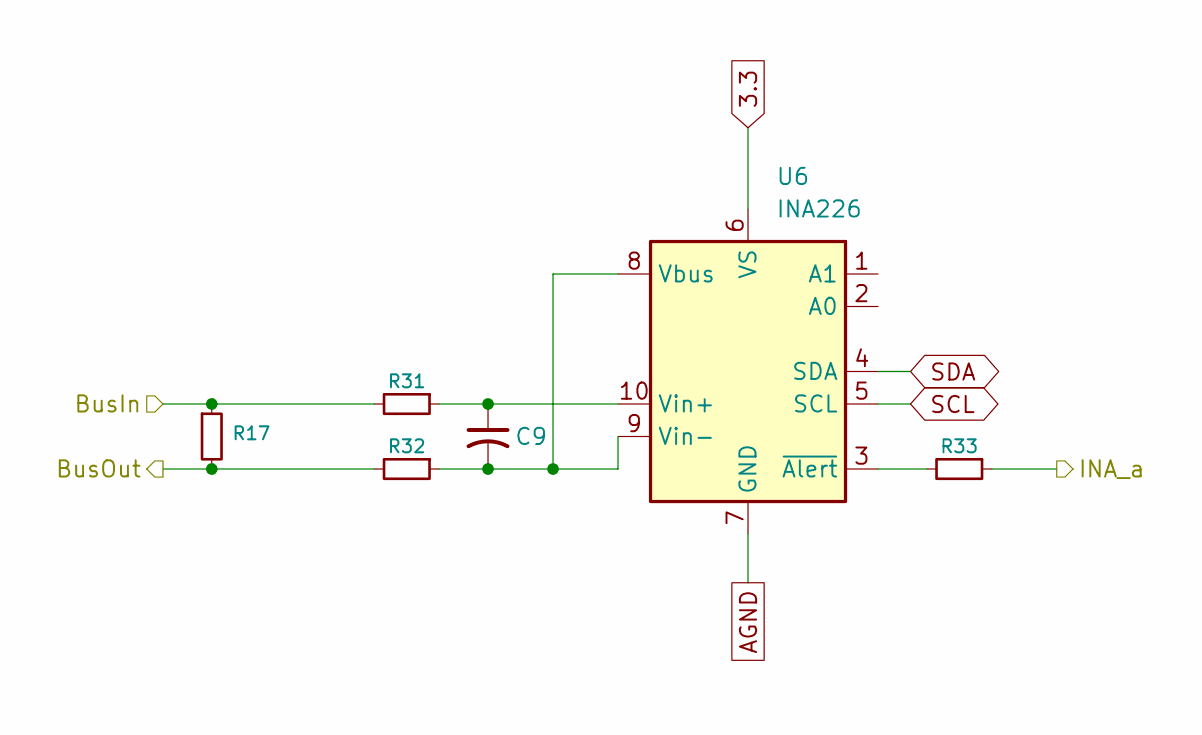
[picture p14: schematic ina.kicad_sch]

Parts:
C9: 0.1; C_0805_2012Metric_Pad1.18x1.45mm_HandSolder
R17: WSL2512R0470FEA; R_2512_6332Metric_Pad1.40x3.35mm_HandSolder
R31, R32: 10; R_0805_2012Metric_Pad1.20x1.40mm_HandSolder
R33: 1k; R_0805_2012Metric_Pad1.20x1.40mm_HandSolder
U6: INA226; VSSOP-10_3x3mm_P0.5mm

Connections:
3.3: U6.6 (VS); also elsewhere on the board
/esp/INA_a: R33.1; also elsewhere on the board
/fans/INA/BusIn: R17.1, R31.2; also elsewhere on the board
/fans/INA/BusOut: R17.2, R32.2; also elsewhere on the board
AGND: U6.7 (GND); also elsewhere on the board
unnamed: C9.2, R32.1, U6.8 (Vbus), U6.9 (Vin-)
unnamed: C9.1, R31.1, U6.10 (Vin+)
unnamed: R33.2, U6.3 (~Alert)
SCL: U6.5 (SCL); also elsewhere on the board
SDA: U6.4 (SDA); also elsewhere on the board

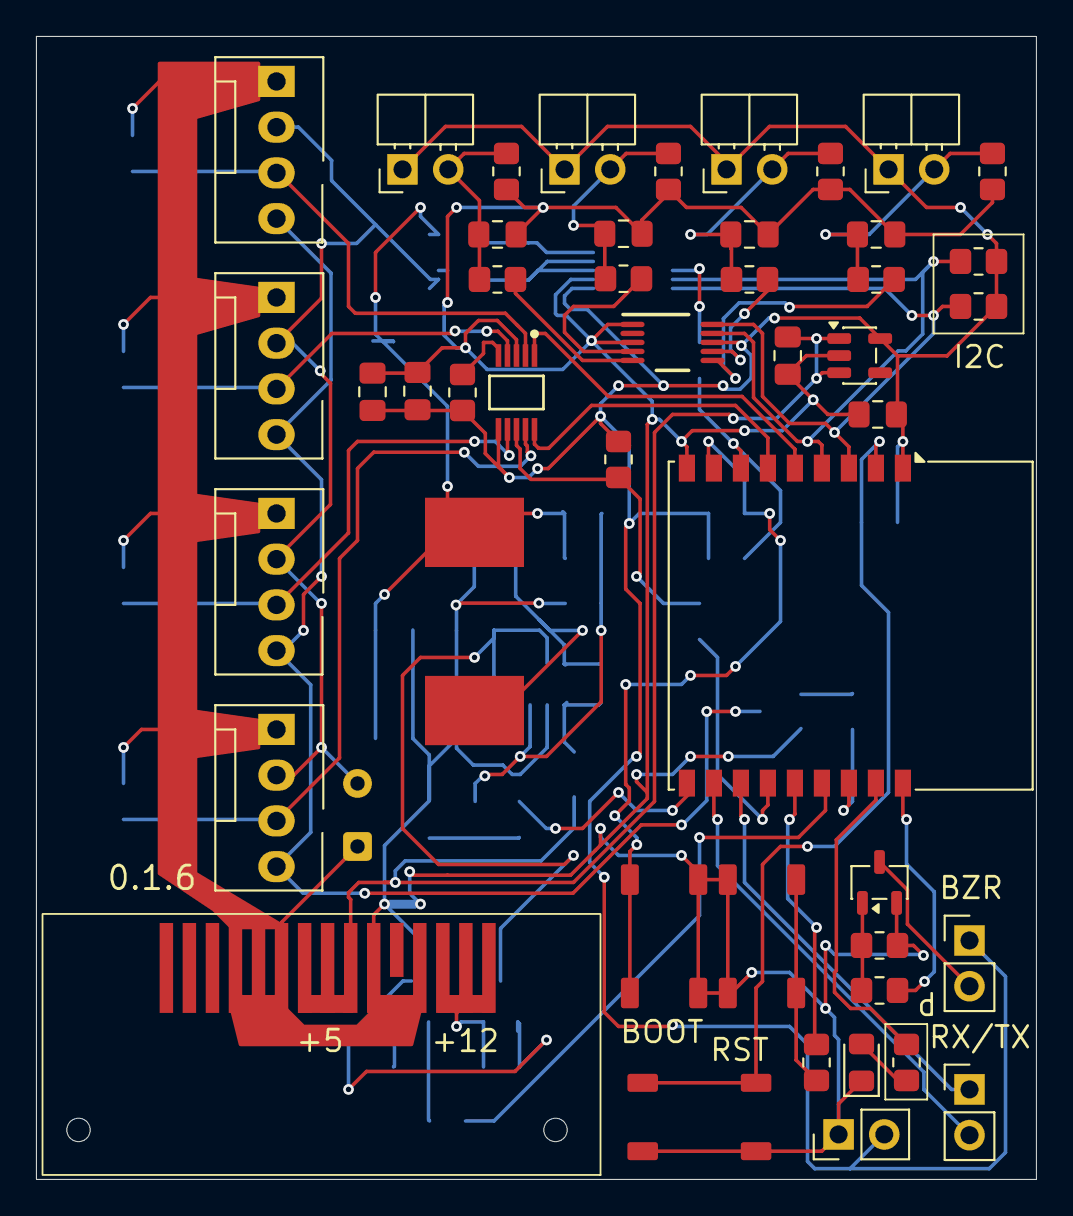
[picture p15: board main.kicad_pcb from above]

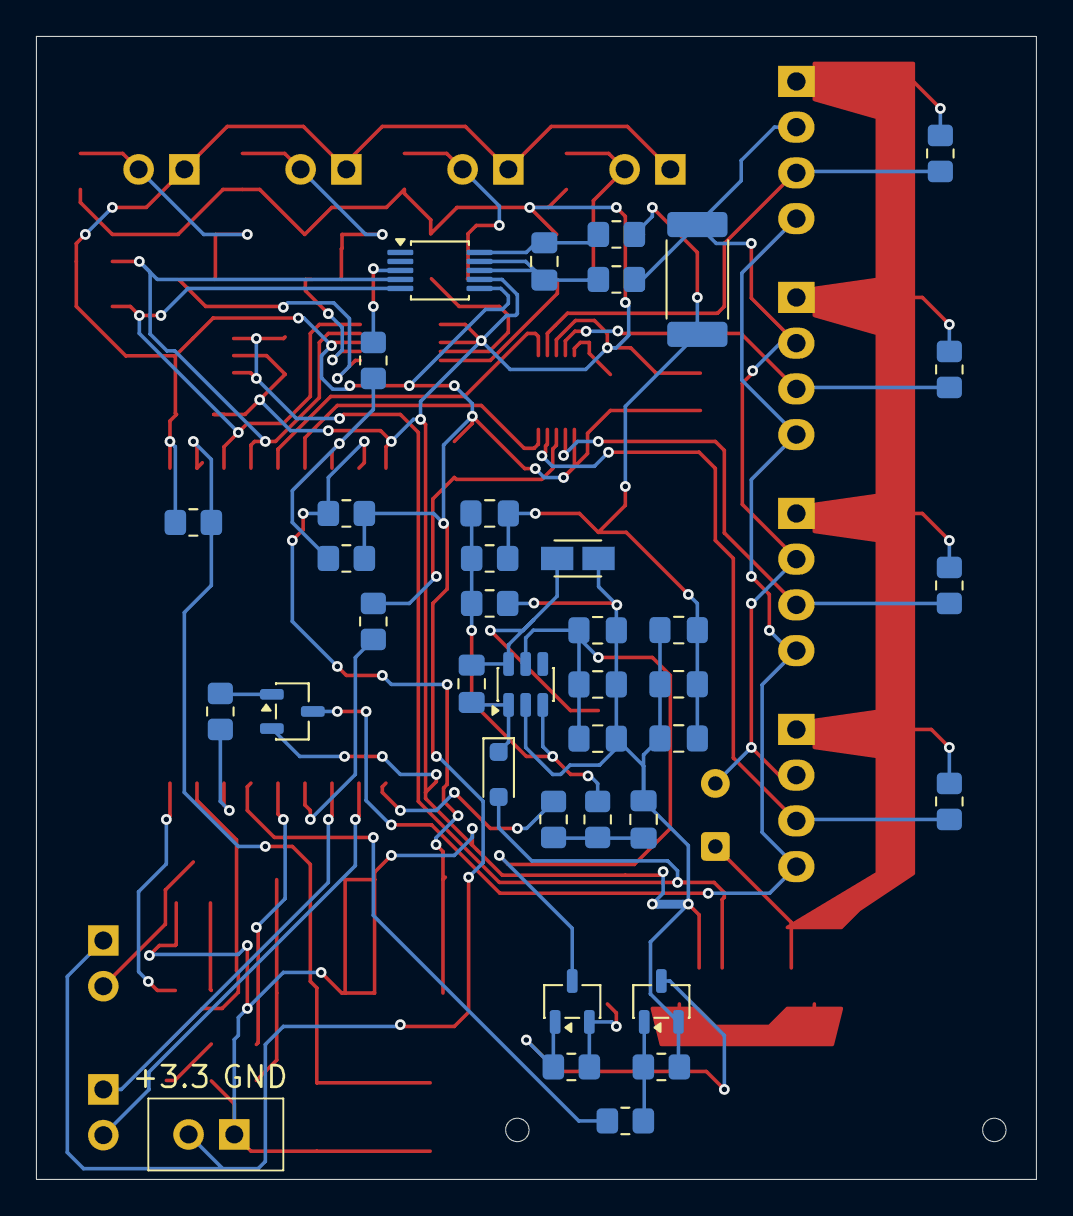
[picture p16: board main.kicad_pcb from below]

Board: 2 copper layers, 55.6 x 63.5 mm, 85 parts (38 on the bottom side), 53 nets.

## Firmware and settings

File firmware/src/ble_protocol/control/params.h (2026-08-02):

#ifndef PARAMS_H
#define PARAMS_H

#include <stdbool.h>
#include <stddef.h>
#include <stdint.h>

#ifdef __cplusplus
extern "C" {
#endif

#define PARAMS_VERSION 6
#define PARAMS_PAYLOAD_LEN 26
#define PARAMS_STATUS_LEN 3

#define PARAM_STATUS_OK 0x00
#define PARAM_STATUS_INVALID 0x01
#define PARAM_STATUS_BUSY 0x02

#define PARAM_FIELD_FAN_MIN_SPEED 0
#define PARAM_FIELD_FAN_CONTROL_TYPE 1
#define PARAM_FIELD_FAN_MAX_TEMP 2
#define PARAM_FIELD_FAN_OFF_DELTA 3
#define PARAM_FIELD_FAN_START_TEMP 4
#define PARAM_FIELD_FAN_MODE 5
#define PARAM_FIELD_FAN_MONITORING_ENABLED 6
#define PARAM_FIELD_FAN2_MONITORING_ENABLED 7
#define PARAM_FIELD_FAN3_MONITORING_ENABLED 8
#define PARAM_FIELD_FAN4_MONITORING_ENABLED 9
#define PARAM_FIELD_OVERHEAT_ALARM_ENABLED 10
#define PARAM_FIELD_NONE 0xFF

#define PARAM_MASK_FAN_MIN_SPEED (1u << 0)
#define PARAM_MASK_FAN_CONTROL_TYPE (1u << 1)
#define PARAM_MASK_FAN_MAX_TEMP (1u << 2)
#define PARAM_MASK_FAN_OFF_DELTA (1u << 3)
#define PARAM_MASK_FAN_START_TEMP (1u << 4)
#define PARAM_MASK_FAN_MODE (1u << 5)
#define PARAM_MASK_FAN_MONITORING_ENABLED (1u << 6)
#define PARAM_MASK_FAN2_MONITORING_ENABLED (1u << 7)
#define PARAM_MASK_FAN3_MONITORING_ENABLED (1u << 8)
#define PARAM_MASK_FAN4_MONITORING_ENABLED (1u << 9)
#define PARAM_MASK_OVERHEAT_ALARM_ENABLED (1u << 10)
#define PARAM_MASK_ALL (PARAM_MASK_FAN_MIN_SPEED | PARAM_MASK_FAN_CONTROL_TYPE | PARAM_MASK_FAN_MAX_TEMP | \
                        PARAM_MASK_FAN_OFF_DELTA | PARAM_MASK_FAN_START_TEMP | PARAM_MASK_FAN_MODE | \
                        PARAM_MASK_FAN_MONITORING_ENABLED | PARAM_MASK_FAN2_MONITORING_ENABLED | \
                        PARAM_MASK_FAN3_MONITORING_ENABLED | PARAM_MASK_FAN4_MONITORING_ENABLED | \
                        PARAM_MASK_OVERHEAT_ALARM_ENABLED)

#define PARAM_FAN_CONTROL_DC 0
#define PARAM_FAN_CONTROL_PWM 1
#define PARAM_FAN_MODE_CONTINUOUS 0
#define PARAM_FAN_MODE_TEMP_SENSOR 1
#define PARAM_FAN_MODE_INACTIVE 2

typedef struct {
    int32_t fan_min_speed;
    uint8_t fan_control_type;
    int32_t fan_max_temp;
    int32_t fan_off_delta;
    int32_t fan_start_temp;
    uint8_t fan_mode;
    uint8_t fan_monitoring_enabled;
    uint8_t fan2_monitoring_enabled;
    uint8_t fan3_monitoring_enabled;
    uint8_t fan4_monitoring_enabled;
    uint8_t overheat_alarm_enabled;
} params_t;

void params_init(void);

bool params_read(params_t *out);
bool params_write(const params_t *params, uint16_t mask);
bool params_cache_get(params_t *out);

bool params_set_pending_payload(const uint8_t *data, size_t len);
bool params_get_current_payload(uint8_t *out, size_t len);
void params_get_last_status_payload(uint8_t *out, size_t len);
void params_set_last_status(uint8_t status, uint8_t field);
uint8_t params_apply(uint8_t *field_id);
void params_factory_reset(void);

#ifdef __cplusplus
}
#endif

#endif

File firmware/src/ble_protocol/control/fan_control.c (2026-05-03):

#include "fan_control.h"

#include <math.h>

#include "esp_log.h"
#include "esp_timer.h"
#include "driver/gpio.h"
#include "driver/ledc.h"
#include "freertos/FreeRTOS.h"
#include "freertos/task.h"

#include "fan_status_ble.h"
#include "device_status.h"
#include "metrics.h"
#include "operation_manager.h"
#include "overcurrent_monitor.h"
#include "params.h"
#include "state.h"

#define FAN_TAG "fan-ctl"

#define FAN_CHANNEL_SCAN_TIMEOUT_US (METRICS_FAN_CHANNELS * 1000000LL)
#define FAN_START_TIMEOUT_US FAN_CHANNEL_SCAN_TIMEOUT_US
#define FAN_FAIL_TIMEOUT_US FAN_CHANNEL_SCAN_TIMEOUT_US
#define FAN_OVERCURRENT_RECOVERY_STEP_PERCENT 3.0f
#define FAN_OVERCURRENT_RECOVERY_WAIT_US (1 * 1000000LL)
#define FAN_HIGHSIDE_GPIO 3
#define FAN_PWM_GPIO_DC 10
#define FAN_PWM_GPIO_PWM 2
#define FAN_PWM_FREQ_HZ 25000
#define FAN_DC_FREQ_HZ 1000
#define FAN_PWM_RES_BITS LEDC_TIMER_10_BIT
#define FAN_DC_RES_BITS LEDC_TIMER_10_BIT
#define FAN_TEMP_CONTROL_CHANNEL 3
static const ledc_mode_t FAN_PWM_MODE = LEDC_LOW_SPEED_MODE;
static const ledc_channel_t FAN_PWM_CHANNEL_ACTIVE = LEDC_CHANNEL_0;
static const ledc_timer_t FAN_PWM_TIMER = LEDC_TIMER_0;

static uint32_t fan_control_max_duty(ledc_timer_bit_t res_bits) {
    return (1U << (uint32_t)res_bits) - 1U;
}
static operation_type_t fan_control_current_operation(void);
static fan_state_t g_state[METRICS_FAN_CHANNELS];
static int64_t g_state_enter_us[METRICS_FAN_CHANNELS];
static int64_t g_last_rpm_ok_us[METRICS_FAN_CHANNELS];
static fan_state_t g_last_reported[METRICS_FAN_CHANNELS];
static operation_type_t g_last_reported_op = OP_TYPE_NONE;
static bool g_override_active = false;
static operation_type_t g_override_op = OP_TYPE_NONE;
static float g_override_rpm = 0.0f;
static bool g_override_has_control_type = false;
static uint8_t g_override_control_type = PARAM_FAN_CONTROL_DC;
static bool g_cycle_active = false;
static bool g_cycle_limit_locked = false;
static float g_cycle_max_percent = 100.0f;
static bool g_recovery_active = false;
static float g_recovery_probe_percent = 100.0f;
static int64_t g_recovery_next_check_us = 0;
static float g_output_percent = 0.0f;
static uint32_t g_status_seq = 0;
typedef struct {
    fan_state_t state[METRICS_FAN_CHANNELS];
    operation_type_t op;
} fan_status_cache_t;

static void fan_control_cycle_reset(void) {
    g_cycle_active = false;
    g_cycle_limit_locked = false;
    g_cycle_max_percent = 100.0f;
    g_recovery_active = false;
    g_recovery_probe_percent = 100.0f;
    g_recovery_next_check_us = 0;
}

static void fan_control_cycle_start(void) {
    g_cycle_active = true;
    g_cycle_limit_locked = false;
    g_cycle_max_percent = 100.0f;
    g_recovery_active = false;
    g_recovery_probe_percent = 100.0f;
    g_recovery_next_check_us = 0;
}

static void fan_control_begin_overcurrent_recovery(float applied_percent, int64_t now_us) {
    float next_percent = applied_percent - FAN_OVERCURRENT_RECOVERY_STEP_PERCENT;
    if (next_percent < 0.0f) {
        next_percent = 0.0f;
    }
    g_cycle_active = true;
    g_cycle_limit_locked = false;
    g_recovery_active = true;
    g_cycle_max_percent = next_percent;
    g_recovery_probe_percent = next_percent;
    g_recovery_next_check_us = now_us + FAN_OVERCURRENT_RECOVERY_WAIT_US;
    ESP_LOGW(FAN_TAG, "Overcurrent recovery start: applied=%.1f%% next=%.1f%% wait=%lld ms",
             (double)applied_percent,
             (double)g_recovery_probe_percent,
             FAN_OVERCURRENT_RECOVERY_WAIT_US / 1000LL);
}

static void fan_control_finish_overcurrent_recovery(float locked_percent, bool alert_active) {
    if (locked_percent < 0.0f) {
        locked_percent = 0.0f;
    }
    if (locked_percent > 100.0f) {
        locked_percent = 100.0f;
    }
    g_cycle_max_percent = locked_percent;
    g_cycle_limit_locked = true;
    g_recovery_active = false;
    g_recovery_probe_percent = locked_percent;
    g_recovery_next_check_us = 0;
    overcurrent_monitor_clear_latched();
    ESP_LOGW(FAN_TAG, "Overcurrent recovery locked max=%.1f%% alert=%d",
             (double)g_cycle_max_percent, alert_active ? 1 : 0);
}

static float fan_control_apply_cycle_limit(float requested_percent, int64_t now_us) {
    if (!g_recovery_active && requested_percent <= 0.0f) {
        fan_control_cycle_reset();
        return 0.0f;
    }

    if (!g_cycle_active) {
        fan_control_cycle_start();
    }

    float applied_percent = requested_percent;
    if (g_cycle_limit_locked) {
        applied_percent = fminf(applied_percent, g_cycle_max_percent);
    }

    bool alert_active = overcurrent_monitor_latched_active();
    if (alert_active && !g_recovery_active && applied_percent > 0.0f) {
        ESP_LOGW(FAN_TAG, "Overcurrent latched: requested=%.1f%% applied=%.1f%% locked=%d max=%.1f%%",
                 (double)requested_percent,
                 (double)applied_percent,
                 g_cycle_limit_locked ? 1 : 0,
                 (double)g_cycle_max_percent);
        fan_control_begin_overcurrent_recovery(applied_percent, now_us);
    }

    if (g_recovery_active && now_us >= g_recovery_next_check_us) {
        alert_active = overcurrent_monitor_alert_active();
        ESP_LOGW(FAN_TAG, "Overcurrent recovery check: probe=%.1f%% raw_alert=%d",
                 (double)g_recovery_probe_percent,
                 alert_active ? 1 : 0);
        if (alert_active) {
            uint16_t mask_enable = 0;
            if (overcurrent_monitor_read_alert_status(&mask_enable)) {
                ESP_LOGW(FAN_TAG, "Overcurrent recovery sample: mask=0x%04X", mask_enable);
            } else {
                ESP_LOGW(FAN_TAG, "Overcurrent recovery sample: mask/enable read failed");
            }
            if (g_recovery_probe_percent > 0.0f) {
                g_recovery_probe_percent -= FAN_OVERCURRENT_RECOVERY_STEP_PERCENT;
                if (g_recovery_probe_percent < 0.0f) {
                    g_recovery_probe_percent = 0.0f;
                }
            }
            g_cycle_max_percent = g_recovery_probe_percent;
            g_recovery_next_check_us = now_us + FAN_OVERCURRENT_RECOVERY_WAIT_US;
            ESP_LOGW(FAN_TAG, "Overcurrent recovery backoff=%.1f%% alert=1",
                     (double)g_recovery_probe_percent);
        } else {
            fan_control_finish_overcurrent_recovery(g_recovery_probe_percent, false);
        }
    }

    if (g_recovery_active) {
        return g_recovery_probe_percent;
    }
    if (g_cycle_limit_locked) {
        return fminf(requested_percent, g_cycle_max_percent);
    }
    return requested_percent;
}
static fan_status_cache_t g_status_cache = {0};

static void fan_status_cache_write(operation_type_t op) {
    fan_status_cache_t snap = {
        .op = op,
    };
    for (uint8_t ch = 0; ch < METRICS_FAN_CHANNELS; ch++) {
        snap.state[ch] = g_state[ch];
    }
    __atomic_fetch_add(&g_status_seq, 1U, __ATOMIC_ACQ_REL);
    g_status_cache = snap;
    __atomic_fetch_add(&g_status_seq, 1U, __ATOMIC_ACQ_REL);
}
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

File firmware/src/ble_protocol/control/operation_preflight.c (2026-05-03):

#include "operation_preflight.h"

#include <math.h>
#include <stddef.h>

#include "esp_log.h"

#include "fan_control.h"
#include "overcurrent_monitor.h"
#include "params.h"

#define PREFLIGHT_CONFIRM_US (3000 * 1000LL)

static const char *TAG = "op-preflight";

typedef enum {
    PREFLIGHT_PHASE_IDLE = 0,
    PREFLIGHT_PHASE_TEST,
} preflight_phase_t;

static preflight_phase_t g_phase = PREFLIGHT_PHASE_IDLE;
static operation_type_t g_type = OP_TYPE_NONE;
static uint8_t g_tests[2] = {0};
static uint8_t g_test_count = 0;
static uint8_t g_test_index = 0;
static int64_t g_deadline_us = 0;
static operation_preflight_caps_t g_caps = {
    .dc_max_percent = 100.0f,
    .pwm_max_percent = 100.0f,
};

static float preflight_clamp_percent(float value) {
    if (!isfinite(value)) {
        return 100.0f;
    }
    if (value < 0.0f) {
        return 0.0f;
    }
    if (value > 100.0f) {
        return 100.0f;
    }
    return value;
}

static void preflight_store_cap(uint8_t control_type, float cap) {
    cap = preflight_clamp_percent(cap);
    if (control_type == PARAM_FAN_CONTROL_PWM) {
        g_caps.pwm_max_percent = cap;
    } else {
        g_caps.dc_max_percent = cap;
    }
}

static bool preflight_add_test(uint8_t control_type) {
    if (control_type != PARAM_FAN_CONTROL_DC && control_type != PARAM_FAN_CONTROL_PWM) {
        return false;
    }
    for (uint8_t idx = 0; idx < g_test_count; idx++) {
        if (g_tests[idx] == control_type) {
            return true;
        }
    }
    if (g_test_count >= sizeof(g_tests)) {
        return false;
    }
    g_tests[g_test_count++] = control_type;
    return true;
}

static bool preflight_select_tests(operation_type_t type, const char **err_text) {
    g_test_count = 0;
    if (type == OP_TYPE_SETUP_FANS) {
        return preflight_add_test(PARAM_FAN_CONTROL_DC) &&
               preflight_add_test(PARAM_FAN_CONTROL_PWM);
    }

    params_t current;
    if (!(params_cache_get(&current) || params_read(&current))) {
        if (err_text) {
            *err_text = "params read";
        }
        return false;
    }
    return preflight_add_test(current.fan_control_type);
}

static bool preflight_start_current_test(int64_t now_us, const char **err_text) {
    if (g_test_index >= g_test_count) {
        return false;
    }
    uint8_t control_type = g_tests[g_test_index];
    fan_control_cycle_limit_reset();
    if (!fan_control_override_set_output((uint8_t)g_type, control_type, 100.0f)) {
        if (err_text) {
            *err_text = "fan busy";
        }
        return false;
    }
    g_deadline_us = now_us + PREFLIGHT_CONFIRM_US;
    g_phase = PREFLIGHT_PHASE_TEST;
    ESP_LOGI(TAG, "start type=%u control=%u", (unsigned)g_type, (unsigned)control_type);
    return true;
}

void operation_preflight_reset(void) {
    if (g_type != OP_TYPE_NONE) {
        fan_control_override_clear((uint8_t)g_type);
    }
    fan_control_cycle_limit_reset();
    g_phase = PREFLIGHT_PHASE_IDLE;
    g_type = OP_TYPE_NONE;
    g_test_count = 0;
    g_test_index = 0;
    g_deadline_us = 0;
    g_caps.dc_max_percent = 100.0f;
    g_caps.pwm_max_percent = 100.0f;
}

bool operation_preflight_start(operation_type_t type, int64_t now_us, const char **err_text) {
    operation_preflight_reset();
    g_type = type;
    if (err_text) {
        *err_text = NULL;
    }
    if (!preflight_select_tests(type, err_text)) {
        operation_preflight_reset();
        return false;
    }
    return preflight_start_current_test(now_us, err_text);
}

bool operation_preflight_is_active(void) {
    return g_phase != PREFLIGHT_PHASE_IDLE;
}

operation_preflight_result_t operation_preflight_step(int64_t now_us, const char **err_text) {
    if (err_text) {
        *err_text = NULL;
    }
    if (g_phase == PREFLIGHT_PHASE_IDLE) {
        return OP_PREFLIGHT_RESULT_DONE;
    }
    if (g_phase != PREFLIGHT_PHASE_TEST || g_test_index >= g_test_count) {
        if (err_text) {
            *err_text = "preflight state";
        }
        operation_preflight_reset();
        return OP_PREFLIGHT_RESULT_ERROR;
    }
    if (now_us < g_deadline_us ||
        overcurrent_monitor_latched_active() ||
        fan_control_overcurrent_recovery_active()) {
        return OP_PREFLIGHT_RESULT_CONTINUE;
    }

    uint8_t control_type = g_tests[g_test_index];
    float cap = fan_control_cycle_max_percent();
    preflight_store_cap(control_type, cap);
    ESP_LOGI(TAG, "done type=%u control=%u cap=%.1f%%",
             (unsigned)g_type, (unsigned)control_type, (double)cap);

    fan_control_override_clear((uint8_t)g_type);
    fan_control_cycle_limit_reset();
    g_test_index++;

    if (g_test_index < g_test_count) {
        return preflight_start_current_test(now_us, err_text)
                   ? OP_PREFLIGHT_RESULT_CONTINUE
                   : OP_PREFLIGHT_RESULT_ERROR;
    }

    g_phase = PREFLIGHT_PHASE_IDLE;
    g_type = OP_TYPE_NONE;
    return OP_PREFLIGHT_RESULT_DONE;
}

bool operation_preflight_get_caps(operation_preflight_caps_t *out) {
    if (!out) {
        return false;
    }
    *out = g_caps;
    return true;
}

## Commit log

2026-02-24 Improvements, add led for debug
2026-02-24 Add retry for connect button
2026-02-25 Add code for simple server to test push button
2026-02-28 Move config to single file, handle i2c errors
    [ads1115.c, metrics.c]
2026-03-01 Add sensor threshold and init read metrics values
2026-03-02 Add fan speed functional
2026-03-12 Add fan control service and exceptions
2026-03-12 Add calibration operation
2026-03-12 Refactor calibration operation
2026-03-16 Make mock logic for auto-fan control
2026-03-16 Add calibration phase handling
2026-03-22 Fix PWM and DC
    [fan_control.c]
2026-04-12 Fix fan algorithm to control
    [fan_control.c, params.h]
2026-04-22 Add OFF mode for fan
2026-04-23 Add led indicator
2026-04-23 Refactoring device status
2026-04-24 Fix paring mode, add factory reset action
    [params.h]
2026-04-25 Move i2c initialize procedure to independent layer
2026-04-30 Improve INA code, fix overload code
    [ads1115.c, fan_control.c, ina226.c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]
2026-05-29 Rename saved devices
2026-06-01 Fix shared i2c bus
    [ads1115.c, ina226.c, shared_i2c_bus.c]
2026-06-01 Fix speed calculate code
    [metrics.c]
2026-06-13 Fix tests and code structure
    [ads1115.c]
2026-06-13 Add hardware files
    [ads.kicad_sch, esp.kicad_sch, fan_power.kicad_sch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]
2026-06-13 Edit production files
    [main.kicad_pcb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]
2026-06-15 Actualize production files
    [main-B_Adhesive.gbr, main-B_Courtyard.gbr, main-B_Cu.gbr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]
